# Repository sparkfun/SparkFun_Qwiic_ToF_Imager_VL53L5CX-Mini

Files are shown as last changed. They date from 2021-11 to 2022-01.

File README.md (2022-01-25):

SparkFun Qwiic ToF Imager with VL53L5CX
========================================

SparkFun Qwiic Mini ToF Imager - VL53L5CX

[*SparkFun Qwiic Mini ToF Imager - VL53L5CX (SEN-19013)*](https://www.sparkfun.com/products/19013)

The SparkFun Qwiic Mini ToF Imager is a state of the art, 64 pixel Time-of-Flight (ToF) 4 meter ranging sensor built around the VL53L5CX from ST. This _Mini_ version has a footprint that is half the size (0.5 in x 1 in) of our standard [Qwiic VL53L5CX](https://www.sparkfun.com/products/18642). Additionally, we moved the Qwiic connectors to the back of the board in a vertical orientation. These design changes favor mounting applications where the VL53L5CX sensor faces outward from an enclosure or chassis, and keeps your Qwiic cables cleanly tucked away.  

This chip integrates a SPAD array, physical infrared filters, and diffractive optical elements (DOE) to achieve the best ranging performance in various ambient lighting conditions with a range of cover glass materials. Utilizing our handy Qwiic system, no soldering is required to connect it to the rest of your system. However, we still have broken out **some** 0.1"-spaced pins in case you prefer to use a breadboard.

Multizone distance measurements up to 4000mm are possible across all 64 zones with a wide 63° diagonal field-of-view which can be read up to 15Hz. Thanks to ST Histogram patented algorithms, the VL53L5CX is able to detect different objects within the FoV. The Histogram also provides immunity to cover glass crosstalk beyond 60 cm.

Ideal for 3D room mapping, obstacle detection for robotics, gesture recognition, IoT, laser-assisted autofocus, and AR/VR enhancement, the Qwiic connector on this sensor makes integration easy. 

SparkFun labored with love to create this code. Feel like supporting open source hardware? 
Buy a [breakout board](https://www.sparkfun.com/products/14722) from SparkFun!

Repository Contents
-------------------

* **/Documents** - Datasheet and User Manual
* **/Hardware** - Eagle design files (.brd, .sch)

Documentation
--------------
* **[Arduino Library](https://github.com/sparkfun/SparkFun_VL53L5CX_Arduino_Library)** - Library for reading distance in millimeters, signal rate, status, etc.
* **[Hookup Guide](https://learn.sparkfun.com/tutorials/qwiic-tof-imager---vl53l5cx-hookup-guide)** - Hookup guide for the Qwiic ToF Imager VL53L5CX

License Information
-------------------

This product is _**open source**_! 

Please review the LICENSE.md file for license information. 

If you have any questions or concerns on licensing, please contact techsupport@sparkfun.com.

Please use, reuse, and modify these files as you see fit. Please maintain attribution to SparkFun Electronics and release any derivative under the same license.

Distributed as-is; no warranty is given.

- Your friends at SparkFun.

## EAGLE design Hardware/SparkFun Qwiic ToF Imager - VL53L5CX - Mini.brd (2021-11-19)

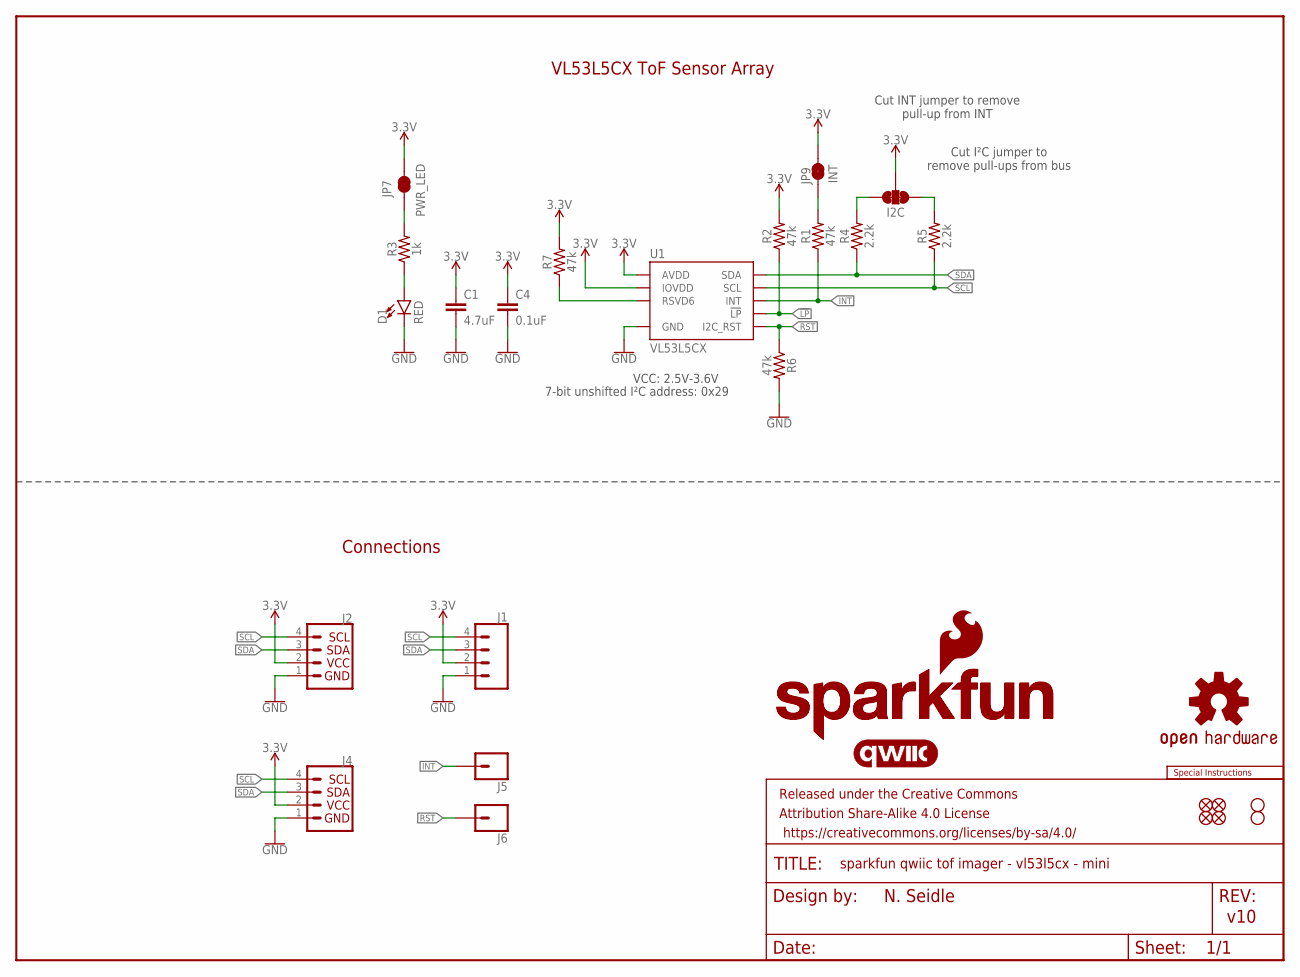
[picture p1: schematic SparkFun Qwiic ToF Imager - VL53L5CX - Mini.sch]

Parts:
C1: 4.7uF; 0402-TIGHT
C4: 0.1uF; 0402-TIGHT
D1: RED; LED-0603
FRAME1: FRAME-LETTER; CREATIVE_COMMONS
I2C: JUMPER-SMT_3_2-NC_TRACE_SILK; SMT-JUMPER_3_2-NC_TRACE_SILK
J1: CONN_041X04_NO_SILK; 1X04_NO_SILK
J2, J4: Vertical Qwiic Connector; JST04_1MM_VERT
J5, J6: CONN_01PTH_NO_SILK_YES_STOP; 1X01_NO_SILK
JP1, JP2, JP5, JP6: FIDUCIALUFIDUCIAL; FIDUCIAL-MICRO
JP7: PWR_LED; SMT-JUMPER_2_NC_TRACE_SILK
JP9: INT; SMT-JUMPER_2_NC_TRACE_SILK
JP10, JP11: STAND-OFF
LOGO1: SFE_LOGO_NAME_FLAME8_MM; SFE_LOGO_NAME_FLAME_8MM
LOGO2: OSHW-LOGONO_SILK; DUMMY
LOGO3: QWIIC_LOGO_CONNECTOR; QWIIC_5.5MM
LOGO4: SFE_LOGO_NAME6_MM; SFE_LOGO_NAME_6MM
LOGO5: SPECIAL_INSTRUCTIONS-ORDERING; ORDERING_INSTRUCTIONS
R1, R2, R6, R7: 47k; 0402-TIGHT
R3: 1k; 0402-TIGHT
R4, R5: 2.2k; 0402-TIGHT
U1: VL53L5CX

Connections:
3.3V: C1.1, C4.1, I2C.2, J1.2, J2.2, J4.2, JP7.2, JP9.2, R2.2, R7.2, U1.A4 (IOVDD), U1.B1 (AVDD), U1.B7 (AVDD)
!LP: R2.1, U1.A5 (!LP)
GND: C1.2, C4.2, D1.C, J1.1, J2.1, J4.1, R6.2, U1.A2 (GND), U1.A6 (GND), U1.A7 (GND), U1.B4 (GND), U1.C1 (GND), U1.C6 (GND), U1.C7 (GND)
INT: J5.1, R1.1, U1.A3 (INT)
unnamed: I2C.1, R5.2
unnamed: I2C.3, R4.2
unnamed: D1.A, R3.1
unnamed: JP9.1, R1.2
unnamed: JP7.1, R3.2
unnamed: R7.1, U1.C2 (RSVD6)
RST: J6.1, R6.1, U1.A1 (I2C_RST)
SCL: J1.4, J2.4, J4.4, R5.1, U1.C4 (SCL)
SDA: J1.3, J2.3, J4.3, R4.1, U1.C3 (SDA)

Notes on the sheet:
N. Seidle
v10
7-bit unshifted I²C address: 0x29
Cut I²C jumper to remove pull-ups from bus
Cut INT jumper to remove pull-up from INT
VCC: 2.5V-3.6V
VL53L5CX ToF Sensor Array
Connections

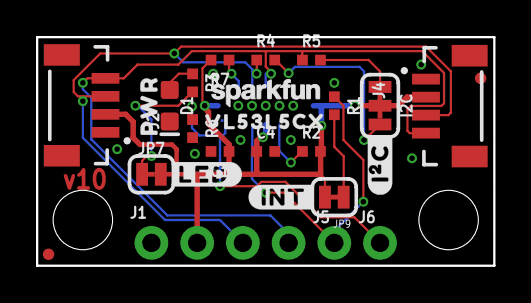
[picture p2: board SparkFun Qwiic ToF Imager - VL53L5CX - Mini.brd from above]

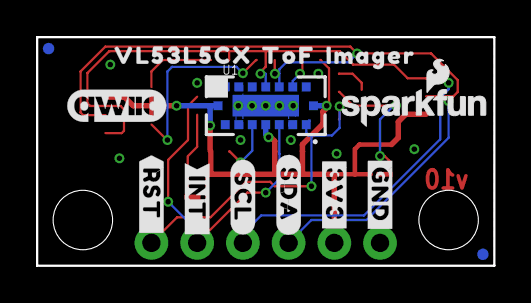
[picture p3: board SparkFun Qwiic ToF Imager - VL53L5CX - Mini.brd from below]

Board: 2 copper layers, 25.4 x 12.7 mm, 45 parts (14 on the bottom side), 13 nets.

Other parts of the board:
U$1: VL53L5CX_0
U$2: #LED#0
U$3: #3V3#13
U$4: PWR12
U$5: #INT#0
U$8: #INT_#0
U$9: #RST_#1
U$16: #I�C#0
U$19: VL53L5CX0
U$20: TOF1
U$22: IMAGER2
U$24: #SCL#1
U$25: #SDA#0
U$30: #GND#62130

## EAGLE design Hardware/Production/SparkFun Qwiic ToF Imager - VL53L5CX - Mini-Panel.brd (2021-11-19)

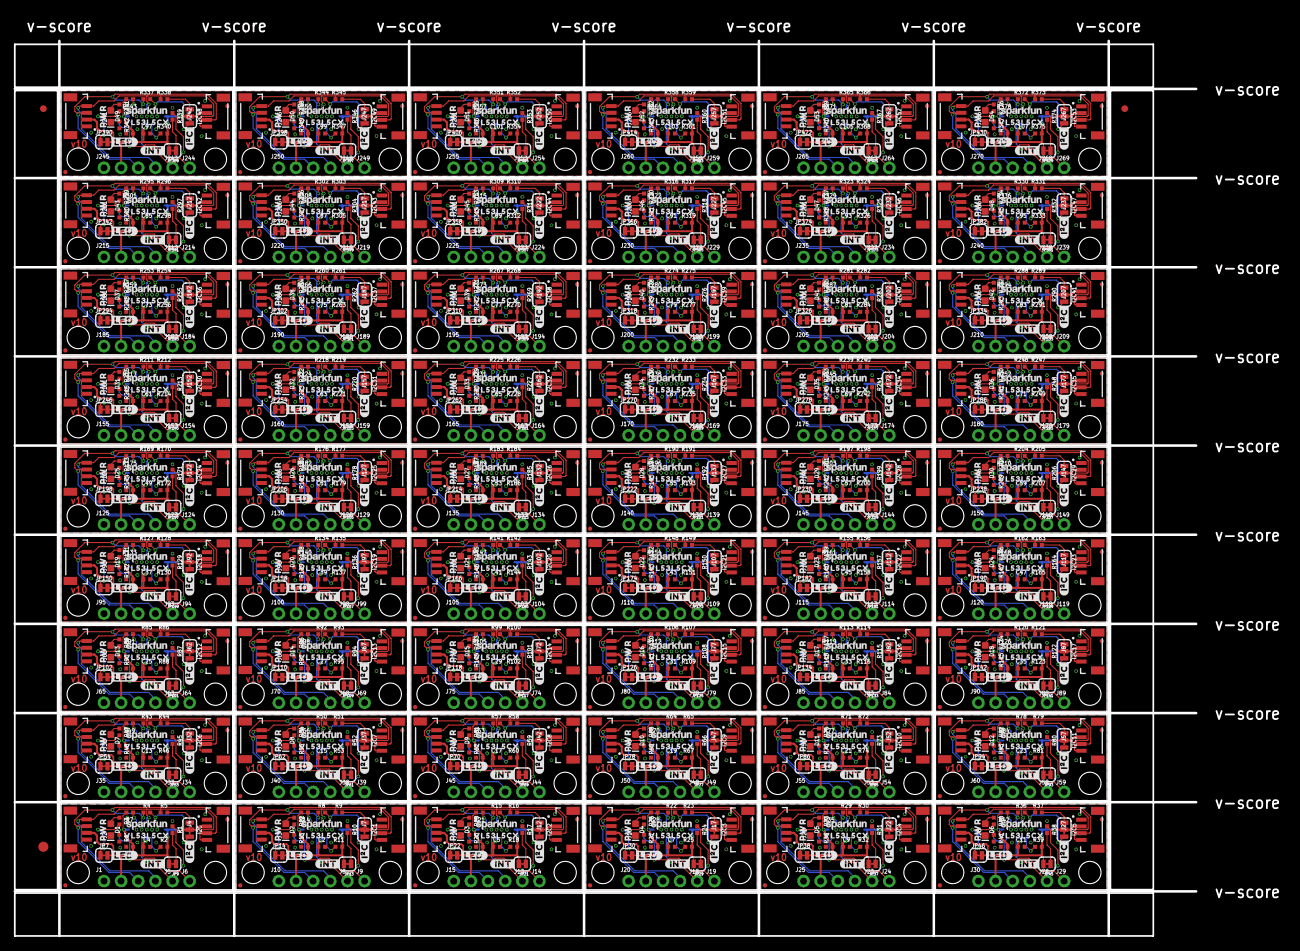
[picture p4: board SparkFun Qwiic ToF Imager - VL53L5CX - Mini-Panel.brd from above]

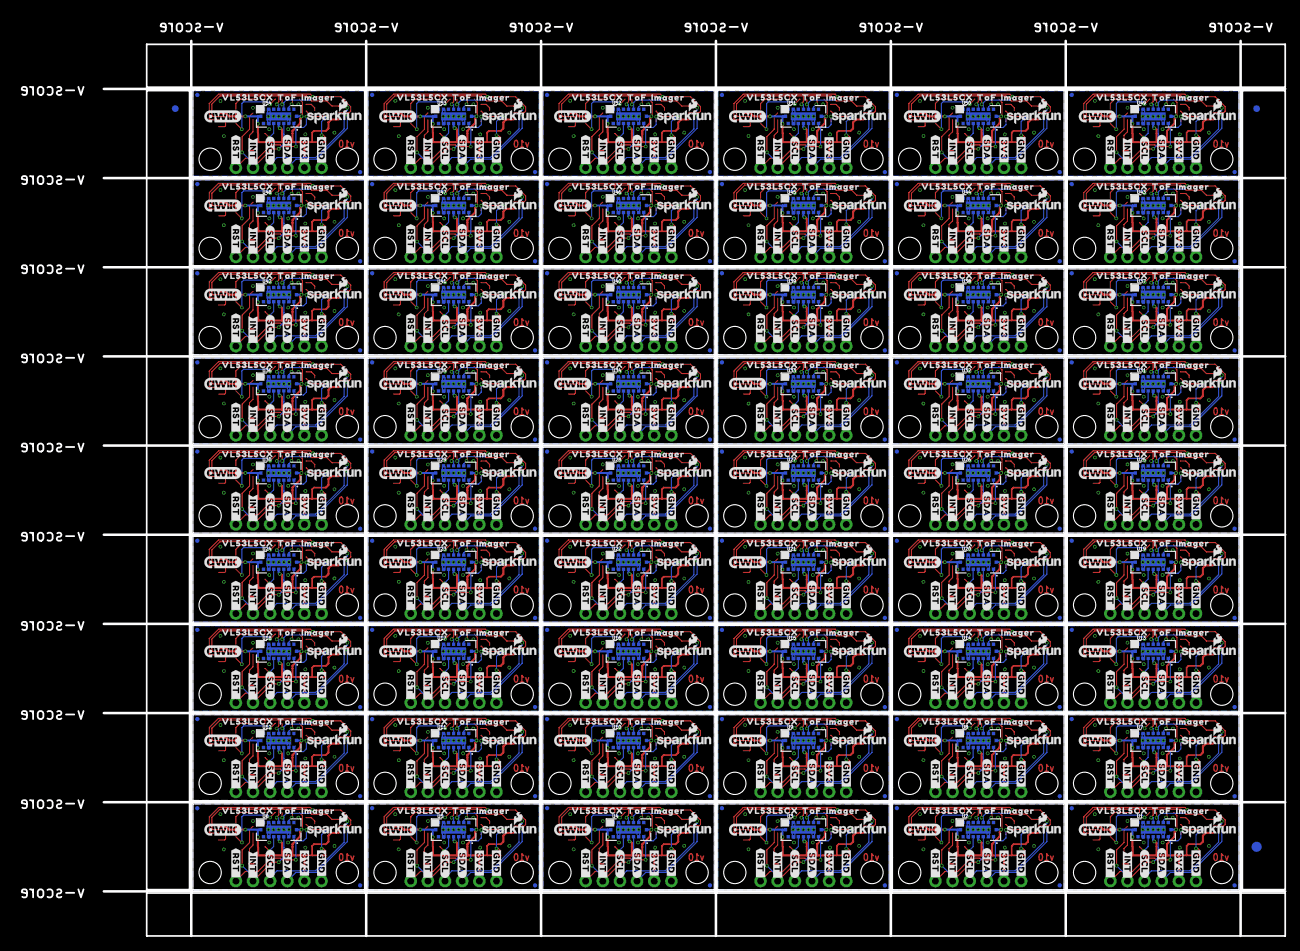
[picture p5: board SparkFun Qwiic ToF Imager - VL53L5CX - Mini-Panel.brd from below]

Board: 2 copper layers, 175.0 x 132.6 mm, 2274 parts (759 on the bottom side), 702 nets.

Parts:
C1, C3, C6, C8, C10, C12, C14, C16, C18, C20, C22, C24, C26, C28, C30, C32, C34, C36, C38, C40, C42, C44, C46, C48, C50, C52, C54, C56, C58, C60, C62, C64, C66, C68, C70, C72, C74, C76, C78, C80, C82, C84, C86, C88, C90, C92, C94, C96, C98, C100, C102, C104, C106, C108: 4.7uF; 0402-TIGHT
C2, C4, C5, C7, C9, C11, C13, C15, C17, C19, C21, C23, C25, C27, C29, C31, C33, C35, C37, C39, C41, C43, C45, C47, C49, C51, C53, C55, C57, C59, C61, C63, C65, C67, C69, C71, C73, C75, C77, C79, C81, C83, C85, C87, C89, C91, C93, C95, C97, C99, C101, C103, C105, C107: 0.1uF; 0402-TIGHT
D1, D2, D3, D4, D5, D6, D7, D8, D9, D10, D11, D12, D13, D14, D15, D16, D17, D18, D19, D20, D21, D22, D23, D24, D25, D26, D27, D28, D29, D30, D31, D32, D33, D34, D35, D36, D37, D38, D39, D40, D41, D42, D43, D44, D45, D46, D47, D48, D49, D50, D51, D52, D53, D54: RED; LED-0603
E$1, E$2, E$3, E$4: FIDUCIAL-1X2
E$5, E$6: FIDUCIAL-1.5X3
I2C, I2C1, I2C2, I2C3, I2C4, I2C5, I2C6, I2C7, I2C8, I2C9, I2C10, I2C11, I2C12, I2C13, I2C14, I2C15, I2C16, I2C17, I2C18, I2C19, I2C20, I2C21, I2C22, I2C23, I2C24, I2C25, I2C26, I2C27, I2C28, I2C29, I2C30, I2C31, I2C32, I2C33, I2C34, I2C35, I2C36, I2C37, I2C38, I2C39, I2C40, I2C41, I2C42, I2C43, I2C44, I2C45, I2C46, I2C47, I2C48, I2C49, I2C50, I2C51, I2C52, I2C53: JUMPER-SMT_3_2-NC_TRACE_SILK; SMT-JUMPER_3_2-NC_TRACE_SILK
J1, J10, J15, J20, J25, J30, J35, J40, J45, J50, J55, J60, J65, J70, J75, J80, J85, J90, J95, J100, J105, J110, J115, J120, J125, J130, J135, J140, J145, J150, J155, J160, J165, J170, J175, J180, J185, J190, J195, J200, J205, J210, J215, J220, J225, J230, J235, J240, J245, J250, J255, J260, J265, J270: 1X04_NO_SILK
J2, J3, J4, J7, J11, J12, J16, J17, J21, J22, J26, J27, J31, J32, J36, J37, J41, J42, J46, J47, J51, J52, J56, J57, J61, J62, J66, J67, J71, J72, J76, J77, J81, J82, J86, J87, J91, J92, J96, J97, J101, J102, J106, J107, J111, J112, J116, J117, J121, J122, J126, J127, J131, J132, J136, J137, J141, J142, J146, J147, J151, J152, J156, J157, J161, J162, J166, J167, J171, J172, J176, J177, J181, J182, J186, J187, J191, J192, J196, J197, J201, J202, J206, J207, J211, J212, J216, J217, J221, J222, J226, J227, J231, J232, J236, J237, J241, J242, J246, J247, J251, J252, J256, J257, J261, J262, J266, J267: Vertical Qwiic Connector; JST04_1MM_VERT
J5, J6, J8, J9, J13, J14, J18, J19, J23, J24, J28, J29, J33, J34, J38, J39, J43, J44, J48, J49, J53, J54, J58, J59, J63, J64, J68, J69, J73, J74, J78, J79, J83, J84, J88, J89, J93, J94, J98, J99, J103, J104, J108, J109, J113, J114, J118, J119, J123, J124, J128, J129, J133, J134, J138, J139, J143, J144, J148, J149, J153, J154, J158, J159, J163, J164, J168, J169, J173, J174, J178, J179, J183, J184, J188, J189, J193, J194, J198, J199, J203, J204, J208, J209, J213, J214, J218, J219, J223, J224, J228, J229, J233, J234, J238, J239, J243, J244, J248, J249, J253, J254, J258, J259, J263, J264, J268, J269: 1X01_NO_SILK
JP1, JP2, JP3, JP4, JP5, JP6, JP8, JP12, JP17, JP18, JP19, JP20, JP25, JP26, JP27, JP28, JP33, JP34, JP35, JP36, JP41, JP42, JP43, JP44, JP49, JP50, JP51, JP52, JP57, JP58, JP59, JP60, JP65, JP66, JP67, JP68, JP73, JP74, JP75, JP76, JP81, JP82, JP83, JP84, JP89, JP90, JP91, JP92, JP97, JP98, JP99, JP100, JP105, JP106, JP107, JP108, JP113, JP114, JP115, JP116, JP121, JP122, JP123, JP124, JP129, JP130, JP131, JP132, JP137, JP138, JP139, JP140, JP145, JP146, JP147, JP148, JP153, JP154, JP155, JP156, JP161, JP162, JP163, JP164, JP169, JP170, JP171, JP172, JP177, JP178, JP179, JP180, JP185, JP186, JP187, JP188, JP193, JP194, JP195, JP196, JP201, JP202, JP203, JP204, JP209, JP210, JP211, JP212, JP217, JP218, JP219, JP220, JP225, JP226, JP227, JP228, JP233, JP234, JP235, JP236, JP241, JP242, JP243, JP244, JP249, JP250, JP251, JP252, JP257, JP258, JP259, JP260, JP265, JP266, JP267, JP268, JP273, JP274, JP275, JP276, JP281, JP282, JP283, JP284, JP289, JP290, JP291, JP292, JP297, JP298, JP299, JP300, JP305, JP306, JP307, JP308, JP313, JP314, JP315, JP316, JP321, JP322, JP323, JP324, JP329, JP330, JP331, JP332, JP337, JP338, JP339, JP340, JP345, JP346, JP347, JP348, JP353, JP354, JP355, JP356, JP361, JP362, JP363, JP364, JP369, JP370, JP371, JP372, JP377, JP378, JP379, JP380, JP385, JP386, JP387, JP388, JP393, JP394, JP395, JP396, JP401, JP402, JP403, JP404, JP409, JP410, JP411, JP412, JP417, JP418, JP419, JP420, JP425, JP426, JP427, JP428: FIDUCIALUFIDUCIAL; FIDUCIAL-MICRO
JP7, JP14, JP22, JP30, JP38, JP46, JP54, JP62, JP70, JP78, JP86, JP94, JP102, JP110, JP118, JP126, JP134, JP142, JP150, JP158, JP166, JP174, JP182, JP190, JP198, JP206, JP214, JP222, JP230, JP238, JP246, JP254, JP262, JP270, JP278, JP286, JP294, JP302, JP310, JP318, JP326, JP334, JP342, JP350, JP358, JP366, JP374, JP382, JP390, JP398, JP406, JP414, JP422, JP430: PWR_LED; SMT-JUMPER_2_NC_TRACE_SILK
JP9, JP13, JP21, JP29, JP37, JP45, JP53, JP61, JP69, JP77, JP85, JP93, JP101, JP109, JP117, JP125, JP133, JP141, JP149, JP157, JP165, JP173, JP181, JP189, JP197, JP205, JP213, JP221, JP229, JP237, JP245, JP253, JP261, JP269, JP277, JP285, JP293, JP301, JP309, JP317, JP325, JP333, JP341, JP349, JP357, JP365, JP373, JP381, JP389, JP397, JP405, JP413, JP421, JP429: INT; SMT-JUMPER_2_NC_TRACE_SILK
JP10, JP11, JP15, JP16, JP23, JP24, JP31, JP32, JP39, JP40, JP47, JP48, JP55, JP56, JP63, JP64, JP71, JP72, JP79, JP80, JP87, JP88, JP95, JP96, JP103, JP104, JP111, JP112, JP119, JP120, JP127, JP128, JP135, JP136, JP143, JP144, JP151, JP152, JP159, JP160, JP167, JP168, JP175, JP176, JP183, JP184, JP191, JP192, JP199, JP200, JP207, JP208, JP215, JP216, JP223, JP224, JP231, JP232, JP239, JP240, JP247, JP248, JP255, JP256, JP263, JP264, JP271, JP272, JP279, JP280, JP287, JP288, JP295, JP296, JP303, JP304, JP311, JP312, JP319, JP320, JP327, JP328, JP335, JP336, JP343, JP344, JP351, JP352, JP359, JP360, JP367, JP368, JP375, JP376, JP383, JP384, JP391, JP392, JP399, JP400, JP407, JP408, JP415, JP416, JP423, JP424, JP431, JP432: STAND-OFF
LOGO1, LOGO6, LOGO9, LOGO12, LOGO15, LOGO18, LOGO21, LOGO24, LOGO27, LOGO30, LOGO33, LOGO36, LOGO39, LOGO42, LOGO45, LOGO48, LOGO51, LOGO54, LOGO57, LOGO60, LOGO63, LOGO66, LOGO69, LOGO72, LOGO75, LOGO78, LOGO81, LOGO84, LOGO87, LOGO90, LOGO93, LOGO96, LOGO99, LOGO102, LOGO105, LOGO108, LOGO111, LOGO114, LOGO117, LOGO120, LOGO123, LOGO126, LOGO129, LOGO132, LOGO135, LOGO138, LOGO141, LOGO144, LOGO147, LOGO150, LOGO153, LOGO156, LOGO159, LOGO162: SFE_LOGO_NAME_FLAME8_MM; SFE_LOGO_NAME_FLAME_8MM
LOGO2, LOGO3, LOGO7, LOGO10, LOGO13, LOGO16, LOGO19, LOGO22, LOGO25, LOGO28, LOGO31, LOGO34, LOGO37, LOGO40, LOGO43, LOGO46, LOGO49, LOGO52, LOGO55, LOGO58, LOGO61, LOGO64, LOGO67, LOGO70, LOGO73, LOGO76, LOGO79, LOGO82, LOGO85, LOGO88, LOGO91, LOGO94, LOGO97, LOGO100, LOGO103, LOGO106, LOGO109, LOGO112, LOGO115, LOGO118, LOGO121, LOGO124, LOGO127, LOGO130, LOGO133, LOGO136, LOGO139, LOGO142, LOGO145, LOGO148, LOGO151, LOGO154, LOGO157, LOGO160: QWIIC_LOGO_CONNECTOR; QWIIC_5.5MM
LOGO4, LOGO5, LOGO8, LOGO11, LOGO14, LOGO17, LOGO20, LOGO23, LOGO26, LOGO29, LOGO32, LOGO35, LOGO38, LOGO41, LOGO44, LOGO47, LOGO50, LOGO53, LOGO56, LOGO59, LOGO62, LOGO65, LOGO68, LOGO71, LOGO74, LOGO77, LOGO80, LOGO83, LOGO86, LOGO89, LOGO92, LOGO95, LOGO98, LOGO101, LOGO104, LOGO107, LOGO110, LOGO113, LOGO116, LOGO119, LOGO122, LOGO125, LOGO128, LOGO131, LOGO134, LOGO137, LOGO140, LOGO143, LOGO146, LOGO149, LOGO152, LOGO155, LOGO158, LOGO161: SFE_LOGO_NAME6_MM; SFE_LOGO_NAME_6MM
R1, R2, R6, R7, R10, R11, R13, R14, R17, R18, R20, R21, R24, R25, R27, R28, R31, R32, R34, R35, R38, R39, R41, R42, R45, R46, R48, R49, R52, R53, R55, R56, R59, R60, R62, R63, R66, R67, R69, R70, R73, R74, R76, R77, R80, R81, R83, R84, R87, R88, R90, R91, R94, R95, R97, R98, R101, R102, R104, R105, R108, R109, R111, R112, R115, R116, R118, R119, R122, R123, R125, R126, R129, R130, R132, R133, R136, R137, R139, R140, R143, R144, R146, R147, R150, R151, R153, R154, R157, R158, R160, R161, R164, R165, R167, R168, R171, R172, R174, R175, R178, R179, R181, R182, R185, R186, R188, R189, R192, R193, R195, R196, R199, R200, R202, R203, R206, R207, R209, R210, R213, R214, R216, R217, R220, R221, R223, R224, R227, R228, R230, R231, R234, R235, R237, R238, R241, R242, R244, R245, R248, R249, R251, R252, R255, R256, R258, R259, R262, R263, R265, R266, R269, R270, R272, R273, R276, R277, R279, R280, R283, R284, R286, R287, R290, R291, R293, R294, R297, R298, R300, R301, R304, R305, R307, R308, R311, R312, R314, R315, R318, R319, R321, R322, R325, R326, R328, R329, R332, R333, R335, R336, R339, R340, R342, R343, R346, R347, R349, R350, R353, R354, R356, R357, R360, R361, R363, R364, R367, R368, R370, R371, R374, R375, R377, R378: 47k; 0402-TIGHT
R3, R12, R19, R26, R33, R40, R47, R54, R61, R68, R75, R82, R89, R96, R103, R110, R117, R124, R131, R138, R145, R152, R159, R166, R173, R180, R187, R194, R201, R208, R215, R222, R229, R236, R243, R250, R257, R264, R271, R278, R285, R292, R299, R306, R313, R320, R327, R334, R341, R348, R355, R362, R369, R376: 1k; 0402-TIGHT
R4, R5, R8, R9, R15, R16, R22, R23, R29, R30, R36, R37, R43, R44, R50, R51, R57, R58, R64, R65, R71, R72, R78, R79, R85, R86, R92, R93, R99, R100, R106, R107, R113, R114, R120, R121, R127, R128, R134, R135, R141, R142, R148, R149, R155, R156, R162, R163, R169, R170, R176, R177, R183, R184, R190, R191, R197, R198, R204, R205, R211, R212, R218, R219, R225, R226, R232, R233, R239, R240, R246, R247, R253, R254, R260, R261, R267, R268, R274, R275, R281, R282, R288, R289, R295, R296, R302, R303, R309, R310, R316, R317, R323, R324, R330, R331, R337, R338, R344, R345, R351, R352, R358, R359, R365, R366, R372, R373: 2.2k; 0402-TIGHT
U1, U2, U3, U4, U5, U6, U7, U8, U9, U10, U11, U12, U13, U14, U15, U16, U17, U18, U19, U20, U21, U22, U23, U24, U25, U26, U27, U28, U29, U30, U31, U32, U33, U34, U35, U36, U37, U38, U39, U40, U41, U42, U43, U44, U45, U46, U47, U48, U49, U50, U51, U52, U53, U54: VL53L5CX
U$1, U$23, U$40, U$54, U$68, U$82, U$96, U$110, U$124, U$138, U$152, U$166, U$180, U$194, U$208, U$222, U$236, U$250, U$264, U$278, U$292, U$306, U$320, U$334, U$348, U$362, U$376, U$390, U$404, U$418, U$432, U$446, U$460, U$474, U$488, U$502, U$516, U$530, U$544, U$558, U$572, U$586, U$600, U$614, U$628, U$642, U$656, U$670, U$684, U$698, U$712, U$726, U$740, U$754: VL53L5CX_0
U$2, U$26, U$41, U$55, U$69, U$83, U$97, U$111, U$125, U$139, U$153, U$167, U$181, U$195, U$209, U$223, U$237, U$251, U$265, U$279, U$293, U$307, U$321, U$335, U$349, U$363, U$377, U$391, U$405, U$419, U$433, U$447, U$461, U$475, U$489, U$503, U$517, U$531, U$545, U$559, U$573, U$587, U$601, U$615, U$629, U$643, U$657, U$671, U$685, U$699, U$713, U$727, U$741, U$755: #LED#0
U$3, U$7, U$29, U$44, U$58, U$72, U$86, U$100, U$114, U$128, U$142, U$156, U$170, U$184, U$198, U$212, U$226, U$240, U$254, U$268, U$282, U$296, U$310, U$324, U$338, U$352, U$366, U$380, U$394, U$408, U$422, U$436, U$450, U$464, U$478, U$492, U$506, U$520, U$534, U$548, U$562, U$576, U$590, U$604, U$618, U$632, U$646, U$660, U$674, U$688, U$702, U$716, U$730, U$744: #3V3#13
U$4, U$10, U$31, U$45, U$59, U$73, U$87, U$101, U$115, U$129, U$143, U$157, U$171, U$185, U$199, U$213, U$227, U$241, U$255, U$269, U$283, U$297, U$311, U$325, U$339, U$353, U$367, U$381, U$395, U$409, U$423, U$437, U$451, U$465, U$479, U$493, U$507, U$521, U$535, U$549, U$563, U$577, U$591, U$605, U$619, U$633, U$647, U$661, U$675, U$689, U$703, U$717, U$731, U$745: PWR12
U$5, U$27, U$42, U$56, U$70, U$84, U$98, U$112, U$126, U$140, U$154, U$168, U$182, U$196, U$210, U$224, U$238, U$252, U$266, U$280, U$294, U$308, U$322, U$336, U$350, U$364, U$378, U$392, U$406, U$420, U$434, U$448, U$462, U$476, U$490, U$504, U$518, U$532, U$546, U$560, U$574, U$588, U$602, U$616, U$630, U$644, U$658, U$672, U$686, U$700, U$714, U$728, U$742, U$756: #INT#0
U$6, U$28, U$30, U$43, U$57, U$71, U$85, U$99, U$113, U$127, U$141, U$155, U$169, U$183, U$197, U$211, U$225, U$239, U$253, U$267, U$281, U$295, U$309, U$323, U$337, U$351, U$365, U$379, U$393, U$407, U$421, U$435, U$449, U$463, U$477, U$491, U$505, U$519, U$533, U$547, U$561, U$575, U$589, U$603, U$617, U$631, U$645, U$659, U$673, U$687, U$701, U$715, U$729, U$743: #GND#62130
U$8, U$11, U$32, U$46, U$60, U$74, U$88, U$102, U$116, U$130, U$144, U$158, U$172, U$186, U$200, U$214, U$228, U$242, U$256, U$270, U$284, U$298, U$312, U$326, U$340, U$354, U$368, U$382, U$396, U$410, U$424, U$438, U$452, U$466, U$480, U$494, U$508, U$522, U$536, U$550, U$564, U$578, U$592, U$606, U$620, U$634, U$648, U$662, U$676, U$690, U$704, U$718, U$732, U$746: #INT_#0
U$9, U$12, U$33, U$47, U$61, U$75, U$89, U$103, U$117, U$131, U$145, U$159, U$173, U$187, U$201, U$215, U$229, U$243, U$257, U$271, U$285, U$299, U$313, U$327, U$341, U$355, U$369, U$383, U$397, U$411, U$425, U$439, U$453, U$467, U$481, U$495, U$509, U$523, U$537, U$551, U$565, U$579, U$593, U$607, U$621, U$635, U$649, U$663, U$677, U$691, U$705, U$719, U$733, U$747: #RST_#1
U$13, U$16, U$34, U$48, U$62, U$76, U$90, U$104, U$118, U$132, U$146, U$160, U$174, U$188, U$202, U$216, U$230, U$244, U$258, U$272, U$286, U$300, U$314, U$328, U$342, U$356, U$370, U$384, U$398, U$412, U$426, U$440, U$454, U$468, U$482, U$496, U$510, U$524, U$538, U$552, U$566, U$580, U$594, U$608, U$622, U$636, U$650, U$664, U$678, U$692, U$706, U$720, U$734, U$748: #I�C#0
U$14, U$19, U$35, U$49, U$63, U$77, U$91, U$105, U$119, U$133, U$147, U$161, U$175, U$189, U$203, U$217, U$231, U$245, U$259, U$273, U$287, U$301, U$315, U$329, U$343, U$357, U$371, U$385, U$399, U$413, U$427, U$441, U$455, U$469, U$483, U$497, U$511, U$525, U$539, U$553, U$567, U$581, U$595, U$609, U$623, U$637, U$651, U$665, U$679, U$693, U$707, U$721, U$735, U$749: VL53L5CX0
U$15, U$20, U$36, U$50, U$64, U$78, U$92, U$106, U$120, U$134, U$148, U$162, U$176, U$190, U$204, U$218, U$232, U$246, U$260, U$274, U$288, U$302, U$316, U$330, U$344, U$358, U$372, U$386, U$400, U$414, U$428, U$442, U$456, U$470, U$484, U$498, U$512, U$526, U$540, U$554, U$568, U$582, U$596, U$610, U$624, U$638, U$652, U$666, U$680, U$694, U$708, U$722, U$736, U$750: TOF1
U$17, U$22, U$37, U$51, U$65, U$79, U$93, U$107, U$121, U$135, U$149, U$163, U$177, U$191, U$205, U$219, U$233, U$247, U$261, U$275, U$289, U$303, U$317, U$331, U$345, U$359, U$373, U$387, U$401, U$415, U$429, U$443, U$457, U$471, U$485, U$499, U$513, U$527, U$541, U$555, U$569, U$583, U$597, U$611, U$625, U$639, U$653, U$667, U$681, U$695, U$709, U$723, U$737, U$751: IMAGER2
U$18, U$24, U$38, U$52, U$66, U$80, U$94, U$108, U$122, U$136, U$150, U$164, U$178, U$192, U$206, U$220, U$234, U$248, U$262, U$276, U$290, U$304, U$318, U$332, U$346, U$360, U$374, U$388, U$402, U$416, U$430, U$444, U$458, U$472, U$486, U$500, U$514, U$528, U$542, U$556, U$570, U$584, U$598, U$612, U$626, U$640, U$654, U$668, U$682, U$696, U$710, U$724, U$738, U$752: #SCL#1
U$21, U$25, U$39, U$53, U$67, U$81, U$95, U$109, U$123, U$137, U$151, U$165, U$179, U$193, U$207, U$221, U$235, U$249, U$263, U$277, U$291, U$305, U$319, U$333, U$347, U$361, U$375, U$389, U$403, U$417, U$431, U$445, U$459, U$473, U$487, U$501, U$515, U$529, U$543, U$557, U$571, U$585, U$599, U$613, U$627, U$641, U$655, U$669, U$683, U$697, U$711, U$725, U$739, U$753: #SDA#0

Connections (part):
3.3V: C1.1, C4.1, I2C.2, J1.2, J2.2, J4.2, JP7.2, JP9.2, R2.2, R7.2, U1.A4, U1.B1, U1.B7
3.3V1: C2.1, C3.1, I2C1.2, J3.2, J7.2, J10.2, JP13.2, JP14.2, R11.2, R14.2, U2.A4, U2.B1, U2.B7
3.3V2: C5.1, C6.1, I2C2.2, J11.2, J12.2, J15.2, JP21.2, JP22.2, R18.2, R21.2, U3.A4, U3.B1, U3.B7
3.3V3: C7.1, C8.1, I2C3.2, J16.2, J17.2, J20.2, JP29.2, JP30.2, R25.2, R28.2, U4.A4, U4.B1, U4.B7
3.3V4: C9.1, C10.1, I2C4.2, J21.2, J22.2, J25.2, JP37.2, JP38.2, R32.2, R35.2, U5.A4, U5.B1, U5.B7
3.3V5: C11.1, C12.1, I2C5.2, J26.2, J27.2, J30.2, JP45.2, JP46.2, R39.2, R42.2, U6.A4, U6.B1, U6.B7
3.3V6: C13.1, C14.1, I2C6.2, J31.2, J32.2, J35.2, JP53.2, JP54.2, R46.2, R49.2, U7.A4, U7.B1, U7.B7
3.3V7: C15.1, C16.1, I2C7.2, J36.2, J37.2, J40.2, JP61.2, JP62.2, R53.2, R56.2, U8.A4, U8.B1, U8.B7
3.3V8: C17.1, C18.1, I2C8.2, J41.2, J42.2, J45.2, JP69.2, JP70.2, R60.2, R63.2, U9.A4, U9.B1, U9.B7
3.3V9: C19.1, C20.1, I2C9.2, J46.2, J47.2, J50.2, JP77.2, JP78.2, R67.2, R70.2, U10.A4, U10.B1, U10.B7
3.3V10: C21.1, C22.1, I2C10.2, J51.2, J52.2, J55.2, JP85.2, JP86.2, R74.2, R77.2, U11.A4, U11.B1, U11.B7
3.3V11: C23.1, C24.1, I2C11.2, J56.2, J57.2, J60.2, JP93.2, JP94.2, R81.2, R84.2, U12.A4, U12.B1, U12.B7
3.3V12: C25.1, C26.1, I2C12.2, J61.2, J62.2, J65.2, JP101.2, JP102.2, R88.2, R91.2, U13.A4, U13.B1, U13.B7
3.3V13: C27.1, C28.1, I2C13.2, J66.2, J67.2, J70.2, JP109.2, JP110.2, R95.2, R98.2, U14.A4, U14.B1, U14.B7
3.3V14: C29.1, C30.1, I2C14.2, J71.2, J72.2, J75.2, JP117.2, JP118.2, R102.2, R105.2, U15.A4, U15.B1, U15.B7
3.3V15: C31.1, C32.1, I2C15.2, J76.2, J77.2, J80.2, JP125.2, JP126.2, R109.2, R112.2, U16.A4, U16.B1, U16.B7
3.3V16: C33.1, C34.1, I2C16.2, J81.2, J82.2, J85.2, JP133.2, JP134.2, R116.2, R119.2, U17.A4, U17.B1, U17.B7
3.3V17: C35.1, C36.1, I2C17.2, J86.2, J87.2, J90.2, JP141.2, JP142.2, R123.2, R126.2, U18.A4, U18.B1, U18.B7
3.3V18: C37.1, C38.1, I2C18.2, J91.2, J92.2, J95.2, JP149.2, JP150.2, R130.2, R133.2, U19.A4, U19.B1, U19.B7
3.3V19: C39.1, C40.1, I2C19.2, J96.2, J97.2, J100.2, JP157.2, JP158.2, R137.2, R140.2, U20.A4, U20.B1, U20.B7
3.3V20: C41.1, C42.1, I2C20.2, J101.2, J102.2, J105.2, JP165.2, JP166.2, R144.2, R147.2, U21.A4, U21.B1, U21.B7
3.3V21: C43.1, C44.1, I2C21.2, J106.2, J107.2, J110.2, JP173.2, JP174.2, R151.2, R154.2, U22.A4, U22.B1, U22.B7
3.3V22: C45.1, C46.1, I2C22.2, J111.2, J112.2, J115.2, JP181.2, JP182.2, R158.2, R161.2, U23.A4, U23.B1, U23.B7
3.3V23: C47.1, C48.1, I2C23.2, J116.2, J117.2, J120.2, JP189.2, JP190.2, R165.2, R168.2, U24.A4, U24.B1, U24.B7
3.3V24: C49.1, C50.1, I2C24.2, J121.2, J122.2, J125.2, JP197.2, JP198.2, R172.2, R175.2, U25.A4, U25.B1, U25.B7
3.3V25: C51.1, C52.1, I2C25.2, J126.2, J127.2, J130.2, JP205.2, JP206.2, R179.2, R182.2, U26.A4, U26.B1, U26.B7
3.3V26: C53.1, C54.1, I2C26.2, J131.2, J132.2, J135.2, JP213.2, JP214.2, R186.2, R189.2, U27.A4, U27.B1, U27.B7
3.3V27: C55.1, C56.1, I2C27.2, J136.2, J137.2, J140.2, JP221.2, JP222.2, R193.2, R196.2, U28.A4, U28.B1, U28.B7
3.3V28: C57.1, C58.1, I2C28.2, J141.2, J142.2, J145.2, JP229.2, JP230.2, R200.2, R203.2, U29.A4, U29.B1, U29.B7
3.3V29: C59.1, C60.1, I2C29.2, J146.2, J147.2, J150.2, JP237.2, JP238.2, R207.2, R210.2, U30.A4, U30.B1, U30.B7
3.3V30: C61.1, C62.1, I2C30.2, J151.2, J152.2, J155.2, JP245.2, JP246.2, R214.2, R217.2, U31.A4, U31.B1, U31.B7
3.3V31: C63.1, C64.1, I2C31.2, J156.2, J157.2, J160.2, JP253.2, JP254.2, R221.2, R224.2, U32.A4, U32.B1, U32.B7
3.3V32: C65.1, C66.1, I2C32.2, J161.2, J162.2, J165.2, JP261.2, JP262.2, R228.2, R231.2, U33.A4, U33.B1, U33.B7
3.3V33: C67.1, C68.1, I2C33.2, J166.2, J167.2, J170.2, JP269.2, JP270.2, R235.2, R238.2, U34.A4, U34.B1, U34.B7
3.3V34: C69.1, C70.1, I2C34.2, J171.2, J172.2, J175.2, JP277.2, JP278.2, R242.2, R245.2, U35.A4, U35.B1, U35.B7
3.3V35: C71.1, C72.1, I2C35.2, J176.2, J177.2, J180.2, JP285.2, JP286.2, R249.2, R252.2, U36.A4, U36.B1, U36.B7
3.3V36: C73.1, C74.1, I2C36.2, J181.2, J182.2, J185.2, JP293.2, JP294.2, R256.2, R259.2, U37.A4, U37.B1, U37.B7
3.3V37: C75.1, C76.1, I2C37.2, J186.2, J187.2, J190.2, JP301.2, JP302.2, R263.2, R266.2, U38.A4, U38.B1, U38.B7
3.3V38: C77.1, C78.1, I2C38.2, J191.2, J192.2, J195.2, JP309.2, JP310.2, R270.2, R273.2, U39.A4, U39.B1, U39.B7
3.3V39: C79.1, C80.1, I2C39.2, J196.2, J197.2, J200.2, JP317.2, JP318.2, R277.2, R280.2, U40.A4, U40.B1, U40.B7
3.3V40: C81.1, C82.1, I2C40.2, J201.2, J202.2, J205.2, JP325.2, JP326.2, R284.2, R287.2, U41.A4, U41.B1, U41.B7
3.3V41: C83.1, C84.1, I2C41.2, J206.2, J207.2, J210.2, JP333.2, JP334.2, R291.2, R294.2, U42.A4, U42.B1, U42.B7
3.3V42: C85.1, C86.1, I2C42.2, J211.2, J212.2, J215.2, JP341.2, JP342.2, R298.2, R301.2, U43.A4, U43.B1, U43.B7
3.3V43: C87.1, C88.1, I2C43.2, J216.2, J217.2, J220.2, JP349.2, JP350.2, R305.2, R308.2, U44.A4, U44.B1, U44.B7
3.3V44: C89.1, C90.1, I2C44.2, J221.2, J222.2, J225.2, JP357.2, JP358.2, R312.2, R315.2, U45.A4, U45.B1, U45.B7
3.3V45: C91.1, C92.1, I2C45.2, J226.2, J227.2, J230.2, JP365.2, JP366.2, R319.2, R322.2, U46.A4, U46.B1, U46.B7
3.3V46: C93.1, C94.1, I2C46.2, J231.2, J232.2, J235.2, JP373.2, JP374.2, R326.2, R329.2, U47.A4, U47.B1, U47.B7
3.3V47: C95.1, C96.1, I2C47.2, J236.2, J237.2, J240.2, JP381.2, JP382.2, R333.2, R336.2, U48.A4, U48.B1, U48.B7
3.3V48: C97.1, C98.1, I2C48.2, J241.2, J242.2, J245.2, JP389.2, JP390.2, R340.2, R343.2, U49.A4, U49.B1, U49.B7
3.3V49: C99.1, C100.1, I2C49.2, J246.2, J247.2, J250.2, JP397.2, JP398.2, R347.2, R350.2, U50.A4, U50.B1, U50.B7
3.3V50: C101.1, C102.1, I2C50.2, J251.2, J252.2, J255.2, JP405.2, JP406.2, R354.2, R357.2, U51.A4, U51.B1, U51.B7
3.3V51: C103.1, C104.1, I2C51.2, J256.2, J257.2, J260.2, JP413.2, JP414.2, R361.2, R364.2, U52.A4, U52.B1, U52.B7
3.3V52: C105.1, C106.1, I2C52.2, J261.2, J262.2, J265.2, JP421.2, JP422.2, R368.2, R371.2, U53.A4, U53.B1, U53.B7
3.3V53: C107.1, C108.1, I2C53.2, J266.2, J267.2, J270.2, JP429.2, JP430.2, R375.2, R378.2, U54.A4, U54.B1, U54.B7
!LP: R2.1, U1.A5
!LP1: R11.1, U2.A5
!LP2: R18.1, U3.A5
!LP3: R25.1, U4.A5
!LP4: R32.1, U5.A5
!LP5: R39.1, U6.A5
!LP6: R46.1, U7.A5
!LP7: R53.1, U8.A5
!LP8: R60.1, U9.A5
!LP9: R67.1, U10.A5
!LP10: R74.1, U11.A5
!LP11: R81.1, U12.A5
!LP12: R88.1, U13.A5
!LP13: R95.1, U14.A5
!LP14: R102.1, U15.A5
!LP15: R109.1, U16.A5
!LP16: R116.1, U17.A5
!LP17: R123.1, U18.A5
!LP18: R130.1, U19.A5
!LP19: R137.1, U20.A5
!LP20: R144.1, U21.A5
!LP21: R151.1, U22.A5
!LP22: R158.1, U23.A5
!LP23: R165.1, U24.A5
!LP24: R172.1, U25.A5
!LP25: R179.1, U26.A5
!LP26: R186.1, U27.A5
!LP27: R193.1, U28.A5
!LP28: R200.1, U29.A5
!LP29: R207.1, U30.A5
!LP30: R214.1, U31.A5
!LP31: R221.1, U32.A5
!LP32: R228.1, U33.A5
!LP33: R235.1, U34.A5
!LP34: R242.1, U35.A5
!LP35: R249.1, U36.A5
!LP36: R256.1, U37.A5
!LP37: R263.1, U38.A5
!LP38: R270.1, U39.A5
!LP39: R277.1, U40.A5
!LP40: R284.1, U41.A5
!LP41: R291.1, U42.A5
!LP42: R298.1, U43.A5
!LP43: R305.1, U44.A5
!LP44: R312.1, U45.A5
!LP45: R319.1, U46.A5
!LP46: R326.1, U47.A5
!LP47: R333.1, U48.A5
!LP48: R340.1, U49.A5
!LP49: R347.1, U50.A5
!LP50: R354.1, U51.A5
!LP51: R361.1, U52.A5
!LP52: R368.1, U53.A5
!LP53: R375.1, U54.A5
GND: C1.2, C4.2, D1.C, J1.1, J2.1, J4.1, R6.2, U1.A2, U1.A6, U1.A7, U1.B4, U1.C1, U1.C6, U1.C7
GND1: C2.2, C3.2, D2.C, J3.1, J7.1, J10.1, R13.2, U2.A2, U2.A6, U2.A7, U2.B4, U2.C1, U2.C6, U2.C7
GND2: C5.2, C6.2, D3.C, J11.1, J12.1, J15.1, R20.2, U3.A2, U3.A6, U3.A7, U3.B4, U3.C1, U3.C6, U3.C7
GND3: C7.2, C8.2, D4.C, J16.1, J17.1, J20.1, R27.2, U4.A2, U4.A6, U4.A7, U4.B4, U4.C1, U4.C6, U4.C7
GND4: C9.2, C10.2, D5.C, J21.1, J22.1, J25.1, R34.2, U5.A2, U5.A6, U5.A7, U5.B4, U5.C1, U5.C6, U5.C7
GND5: C11.2, C12.2, D6.C, J26.1, J27.1, J30.1, R41.2, U6.A2, U6.A6, U6.A7, U6.B4, U6.C1, U6.C6, U6.C7
GND6: C13.2, C14.2, D7.C, J31.1, J32.1, J35.1, R48.2, U7.A2, U7.A6, U7.A7, U7.B4, U7.C1, U7.C6, U7.C7
GND7: C15.2, C16.2, D8.C, J36.1, J37.1, J40.1, R55.2, U8.A2, U8.A6, U8.A7, U8.B4, U8.C1, U8.C6, U8.C7
GND8: C17.2, C18.2, D9.C, J41.1, J42.1, J45.1, R62.2, U9.A2, U9.A6, U9.A7, U9.B4, U9.C1, U9.C6, U9.C7
GND9: C19.2, C20.2, D10.C, J46.1, J47.1, J50.1, R69.2, U10.A2, U10.A6, U10.A7, U10.B4, U10.C1, U10.C6, U10.C7
GND10: C21.2, C22.2, D11.C, J51.1, J52.1, J55.1, R76.2, U11.A2, U11.A6, U11.A7, U11.B4, U11.C1, U11.C6, U11.C7
GND11: C23.2, C24.2, D12.C, J56.1, J57.1, J60.1, R83.2, U12.A2, U12.A6, U12.A7, U12.B4, U12.C1, U12.C6, U12.C7
GND12: C25.2, C26.2, D13.C, J61.1, J62.1, J65.1, R90.2, U13.A2, U13.A6, U13.A7, U13.B4, U13.C1, U13.C6, U13.C7
GND13: C27.2, C28.2, D14.C, J66.1, J67.1, J70.1, R97.2, U14.A2, U14.A6, U14.A7, U14.B4, U14.C1, U14.C6, U14.C7
GND14: C29.2, C30.2, D15.C, J71.1, J72.1, J75.1, R104.2, U15.A2, U15.A6, U15.A7, U15.B4, U15.C1, U15.C6, U15.C7
GND15: C31.2, C32.2, D16.C, J76.1, J77.1, J80.1, R111.2, U16.A2, U16.A6, U16.A7, U16.B4, U16.C1, U16.C6, U16.C7
GND16: C33.2, C34.2, D17.C, J81.1, J82.1, J85.1, R118.2, U17.A2, U17.A6, U17.A7, U17.B4, U17.C1, U17.C6, U17.C7
GND17: C35.2, C36.2, D18.C, J86.1, J87.1, J90.1, R125.2, U18.A2, U18.A6, U18.A7, U18.B4, U18.C1, U18.C6, U18.C7
GND18: C37.2, C38.2, D19.C, J91.1, J92.1, J95.1, R132.2, U19.A2, U19.A6, U19.A7, U19.B4, U19.C1, U19.C6, U19.C7
GND19: C39.2, C40.2, D20.C, J96.1, J97.1, J100.1, R139.2, U20.A2, U20.A6, U20.A7, U20.B4, U20.C1, U20.C6, U20.C7
GND20: C41.2, C42.2, D21.C, J101.1, J102.1, J105.1, R146.2, U21.A2, U21.A6, U21.A7, U21.B4, U21.C1, U21.C6, U21.C7
GND21: C43.2, C44.2, D22.C, J106.1, J107.1, J110.1, R153.2, U22.A2, U22.A6, U22.A7, U22.B4, U22.C1, U22.C6, U22.C7
GND22: C45.2, C46.2, D23.C, J111.1, J112.1, J115.1, R160.2, U23.A2, U23.A6, U23.A7, U23.B4, U23.C1, U23.C6, U23.C7
GND23: C47.2, C48.2, D24.C, J116.1, J117.1, J120.1, R167.2, U24.A2, U24.A6, U24.A7, U24.B4, U24.C1, U24.C6, U24.C7
GND24: C49.2, C50.2, D25.C, J121.1, J122.1, J125.1, R174.2, U25.A2, U25.A6, U25.A7, U25.B4, U25.C1, U25.C6, U25.C7
GND25: C51.2, C52.2, D26.C, J126.1, J127.1, J130.1, R181.2, U26.A2, U26.A6, U26.A7, U26.B4, U26.C1, U26.C6, U26.C7
GND26: C53.2, C54.2, D27.C, J131.1, J132.1, J135.1, R188.2, U27.A2, U27.A6, U27.A7, U27.B4, U27.C1, U27.C6, U27.C7
GND27: C55.2, C56.2, D28.C, J136.1, J137.1, J140.1, R195.2, U28.A2, U28.A6, U28.A7, U28.B4, U28.C1, U28.C6, U28.C7
GND28: C57.2, C58.2, D29.C, J141.1, J142.1, J145.1, R202.2, U29.A2, U29.A6, U29.A7, U29.B4, U29.C1, U29.C6, U29.C7
GND29: C59.2, C60.2, D30.C, J146.1, J147.1, J150.1, R209.2, U30.A2, U30.A6, U30.A7, U30.B4, U30.C1, U30.C6, U30.C7
GND30: C61.2, C62.2, D31.C, J151.1, J152.1, J155.1, R216.2, U31.A2, U31.A6, U31.A7, U31.B4, U31.C1, U31.C6, U31.C7
GND31: C63.2, C64.2, D32.C, J156.1, J157.1, J160.1, R223.2, U32.A2, U32.A6, U32.A7, U32.B4, U32.C1, U32.C6, U32.C7
GND32: C65.2, C66.2, D33.C, J161.1, J162.1, J165.1, R230.2, U33.A2, U33.A6, U33.A7, U33.B4, U33.C1, U33.C6, U33.C7
GND33: C67.2, C68.2, D34.C, J166.1, J167.1, J170.1, R237.2, U34.A2, U34.A6, U34.A7, U34.B4, U34.C1, U34.C6, U34.C7
GND34: C69.2, C70.2, D35.C, J171.1, J172.1, J175.1, R244.2, U35.A2, U35.A6, U35.A7, U35.B4, U35.C1, U35.C6, U35.C7
GND35: C71.2, C72.2, D36.C, J176.1, J177.1, J180.1, R251.2, U36.A2, U36.A6, U36.A7, U36.B4, U36.C1, U36.C6, U36.C7
GND36: C73.2, C74.2, D37.C, J181.1, J182.1, J185.1, R258.2, U37.A2, U37.A6, U37.A7, U37.B4, U37.C1, U37.C6, U37.C7
GND37: C75.2, C76.2, D38.C, J186.1, J187.1, J190.1, R265.2, U38.A2, U38.A6, U38.A7, U38.B4, U38.C1, U38.C6, U38.C7
GND38: C77.2, C78.2, D39.C, J191.1, J192.1, J195.1, R272.2, U39.A2, U39.A6, U39.A7, U39.B4, U39.C1, U39.C6, U39.C7
GND39: C79.2, C80.2, D40.C, J196.1, J197.1, J200.1, R279.2, U40.A2, U40.A6, U40.A7, U40.B4, U40.C1, U40.C6, U40.C7
GND40: C81.2, C82.2, D41.C, J201.1, J202.1, J205.1, R286.2, U41.A2, U41.A6, U41.A7, U41.B4, U41.C1, U41.C6, U41.C7
GND41: C83.2, C84.2, D42.C, J206.1, J207.1, J210.1, R293.2, U42.A2, U42.A6, U42.A7, U42.B4, U42.C1, U42.C6, U42.C7
GND42: C85.2, C86.2, D43.C, J211.1, J212.1, J215.1, R300.2, U43.A2, U43.A6, U43.A7, U43.B4, U43.C1, U43.C6, U43.C7
GND43: C87.2, C88.2, D44.C, J216.1, J217.1, J220.1, R307.2, U44.A2, U44.A6, U44.A7, U44.B4, U44.C1, U44.C6, U44.C7
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

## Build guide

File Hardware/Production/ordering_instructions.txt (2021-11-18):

panel size, 169x133mm
PCB thickness, 0.8mm
number of layers, 2
soldermask color, Red
silkscreen color, White
oz copper, 1oz
finish, HASL lead free
stencils, none
pcs per panel, 54
min trace width, 0.1270mm / 0.0050in
min drill size, 0.3048mm / 0.0120in

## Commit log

2021-11-18 Fix small changes from design review. Add panel.
    [SparkFun Qwiic ToF Imager - VL53L5CX - Mini-Panel.brd, SparkFun Qwiic ToF Imager - VL53L5CX - Mini.brd, SparkFun Qwiic ToF Imager - VL53L5CX - Mini.sch]
2021-11-19 Add v10 production files
    [SparkFun Qwiic ToF Imager - VL53L5CX - Mini-Panel.brd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]

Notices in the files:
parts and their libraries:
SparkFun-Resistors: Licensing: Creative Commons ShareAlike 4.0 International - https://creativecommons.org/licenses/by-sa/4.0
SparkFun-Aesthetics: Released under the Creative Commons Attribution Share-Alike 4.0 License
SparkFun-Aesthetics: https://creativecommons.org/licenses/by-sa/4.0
